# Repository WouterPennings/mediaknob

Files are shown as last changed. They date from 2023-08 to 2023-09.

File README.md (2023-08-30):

# Mediaknob

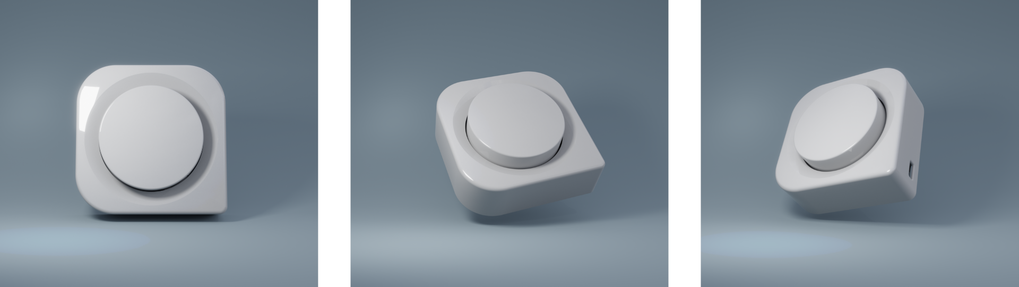
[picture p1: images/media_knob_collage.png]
mediaknob


This is a DIY media control knob for your computer. Adjust your volume, skip songs, or press & hold the knob for attention mode. 

Print the parts, solder the components, and upload the firmware. Go to [instruction.md](instructions.md) to see how to assemble and run the Mediaknob.

## Features

- **Turn Clockwise**: Turn volume up
- **Turn Counter-Clockwise**: Turn volume down
- **Single Click**: Pause/Play
- **Double Click**: Next song
- **Tripple Click**: Previous song
- **Long Click Hold**: Attention mode (Mutes volume while the button is pressed) 

## Acknowledgements

The knob is our first try at building a physical device. Although this is very different, the initial inspiration came from the [Smartknob](https://youtu.be/ip641WmY4pA?si=oMXHZ1xV06TqFzg1). This project was a relatively simple test to get our feet wet in 3D printing and electronics.

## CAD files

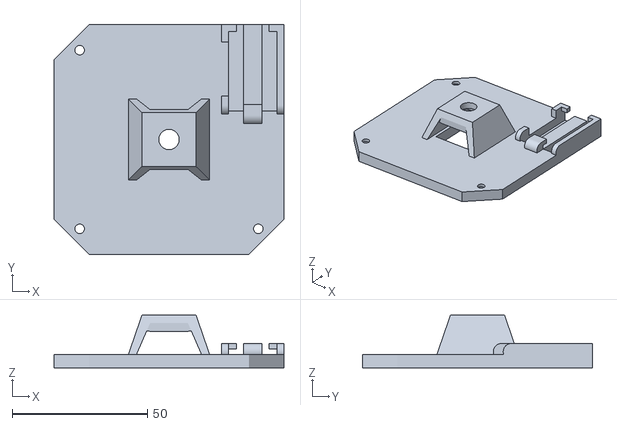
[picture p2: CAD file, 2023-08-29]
3d/main_board.stl
85.0 x 85.0 x 19.5

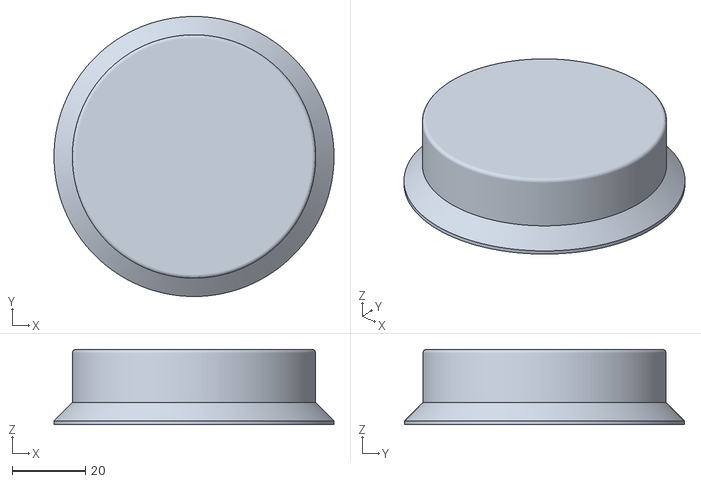
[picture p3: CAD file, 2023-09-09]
3d/button_wide.stl
76.5 x 76.5 x 20.5

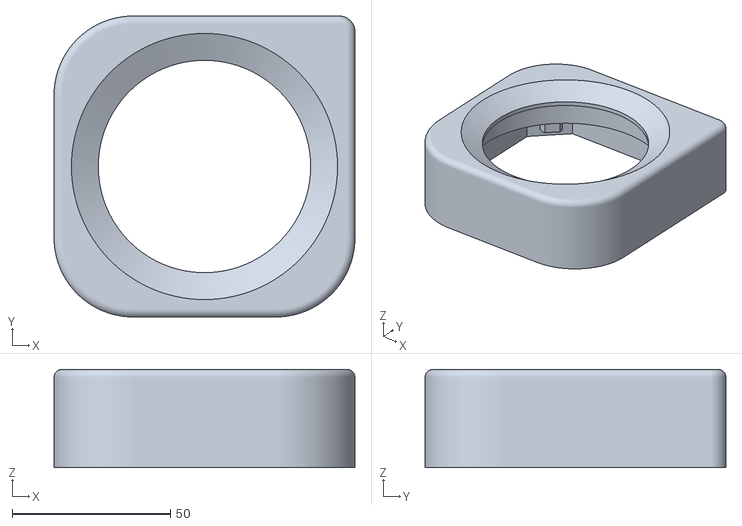
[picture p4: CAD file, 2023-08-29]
3d/chassis.stl
95.0 x 95.0 x 31.0

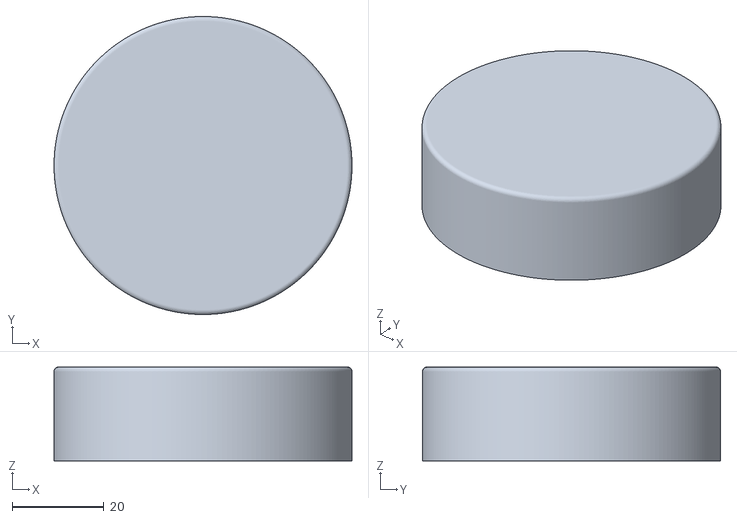
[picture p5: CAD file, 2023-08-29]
3d/button.stl
65.0 x 65.0 x 20.5

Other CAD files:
3d/mediaknob.f3d

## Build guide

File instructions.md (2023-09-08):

# Instructions

You will find the component list, schematics, and instructions to build the media knob here.

## Components

- Arduino Pro Micro 5V ([Sparkfun](https://www.sparkfun.com/products/12640))
  - Make sure you buy a Pro Micro with identical dimensions to the Sparkfun one
- EC11 Rotary encoder ([Aliexpress](https://nl.aliexpress.com/item/1005002802225957.html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))
- All 3D printed parts STL files can be found in [3d](/3d)
- Some electrical wire or five jumper wires
- M3 nuts + M3&ast;20 bolts (M3&ast;10 bolts are also fine, but not preferred as M3&ast;20 bite into the plastic creating a more secure bond.)
- Micro USB cable

### Equipment

- 3D printer, or use a 3D printing service.
- Soldering iron
- Solder
- Flux, not necessary, but could help
- Hex driver

## Electrical Schematic

The pins of the rotary encoder in this schematic are connected to `D2`, `D4`, and `D6`. You could use other pins, even the analog ones; however, you would have to refactor the code accordingly.

<div>
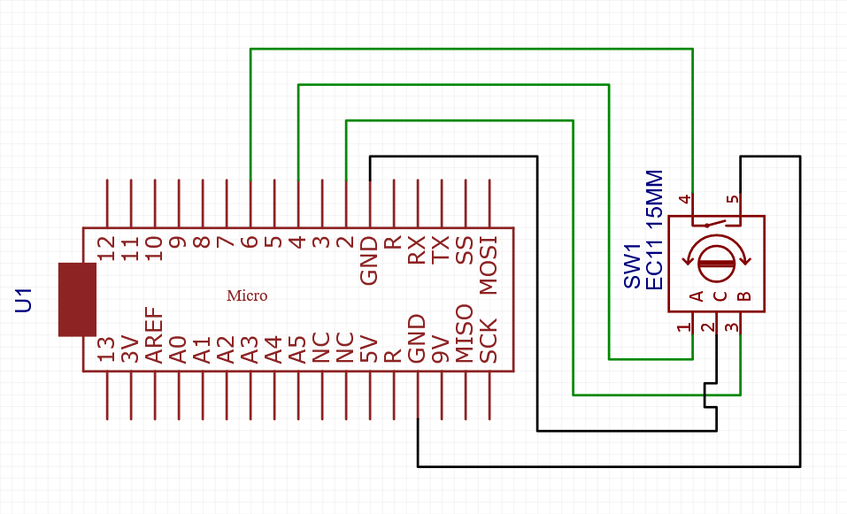
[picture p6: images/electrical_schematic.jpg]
  
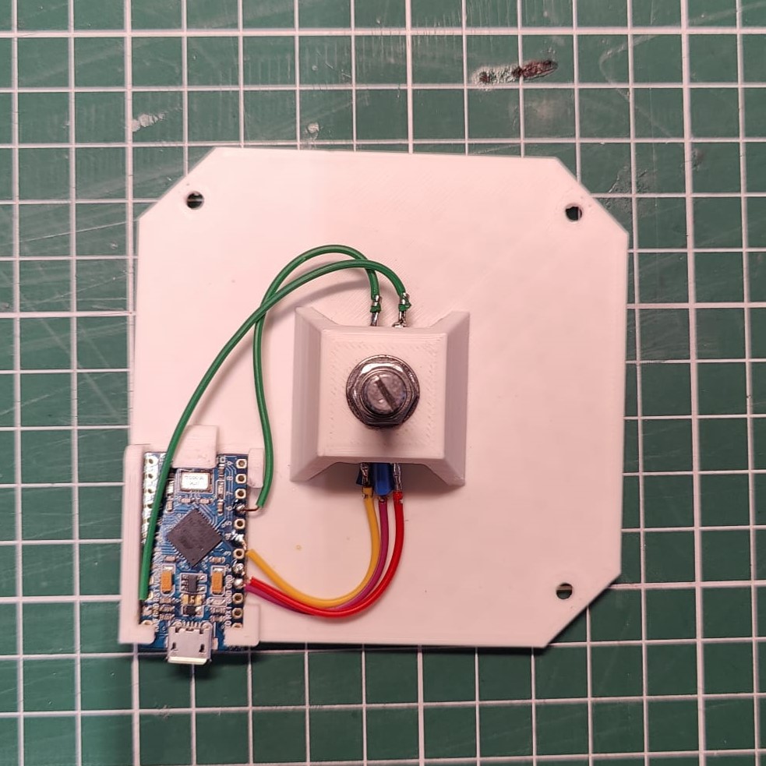
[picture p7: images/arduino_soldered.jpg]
  
</div>

## Assembly Guide

1. 3D print all the components.
   - **Tip**: To achieve a more premium and robust feel, increase the infill or even set it to 100%, as that will increase the weight and structural integrity of the chassis of the button.
2. Melt one M3 nut into each pillar of the [chassis](3d/chassis.stl) using a hot soldering iron.

<div>
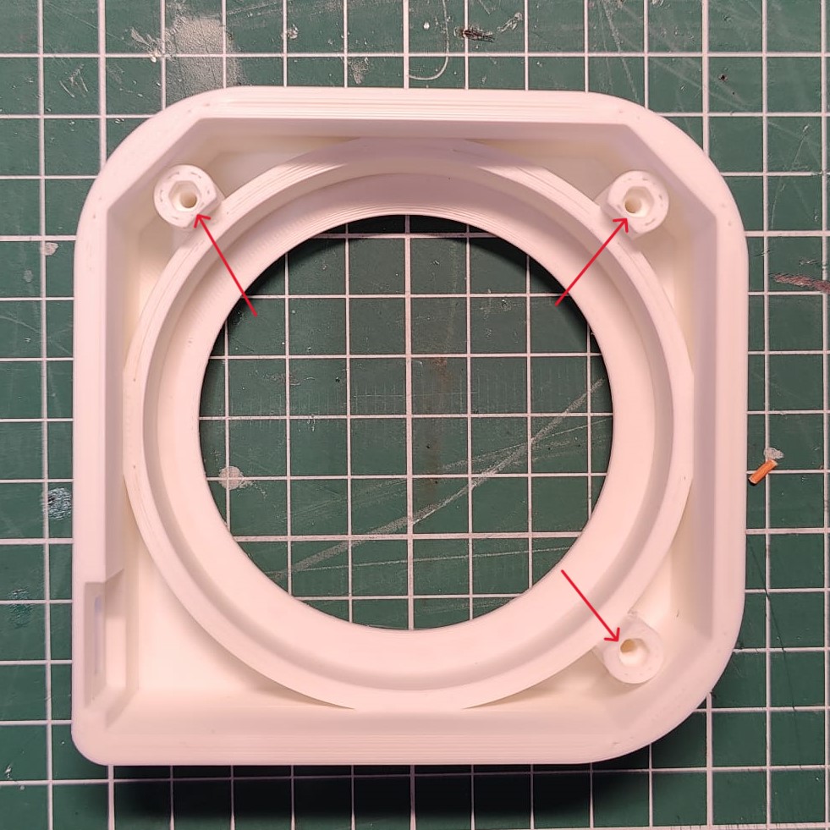
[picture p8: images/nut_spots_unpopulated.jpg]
   
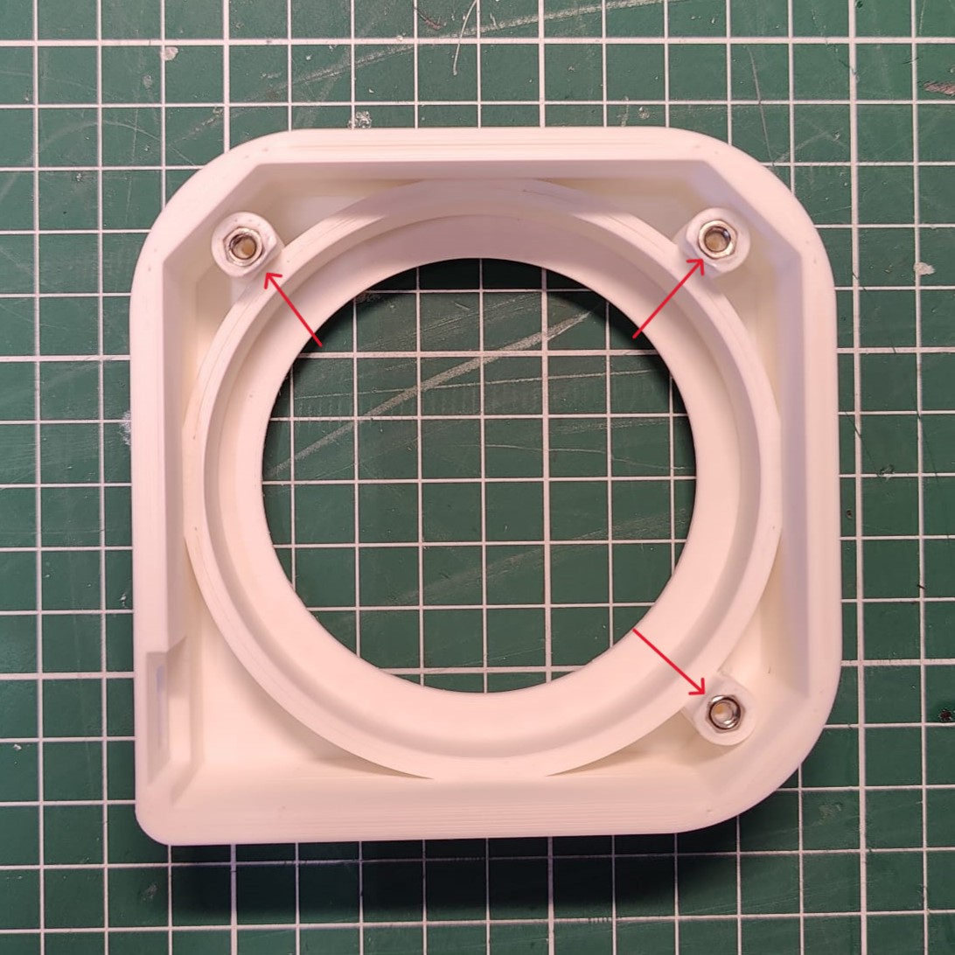
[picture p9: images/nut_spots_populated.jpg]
   
</div>

3. Screw the rotary encoder into the [main board](3d/main_board.stl), and insert the Arduino Pro Micro into its slot.

<div>
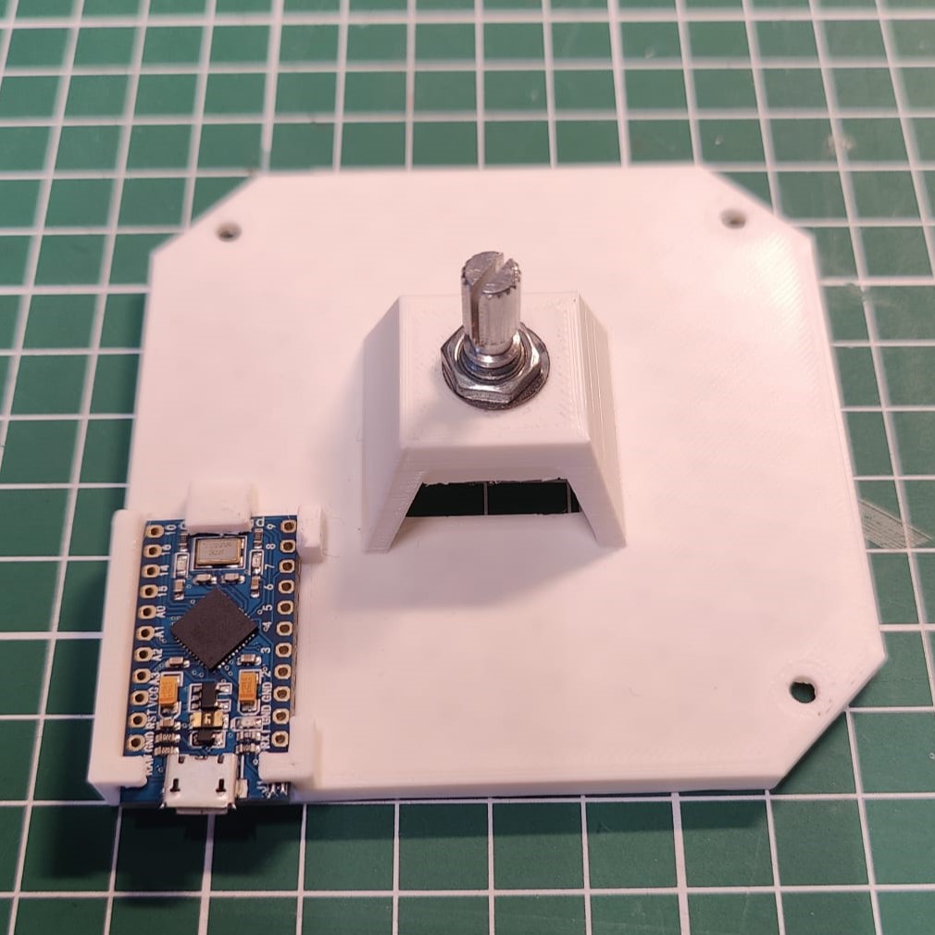
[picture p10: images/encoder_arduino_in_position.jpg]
   
</div>

4. Bend the pins of the rotary encoder so they are pointing outwards to make soldering of the wires easier. The best and safest way to achieve this is with a flat head screw driver, with which you carefully pry the pins away from the encoder plastic enclosure.

<div>
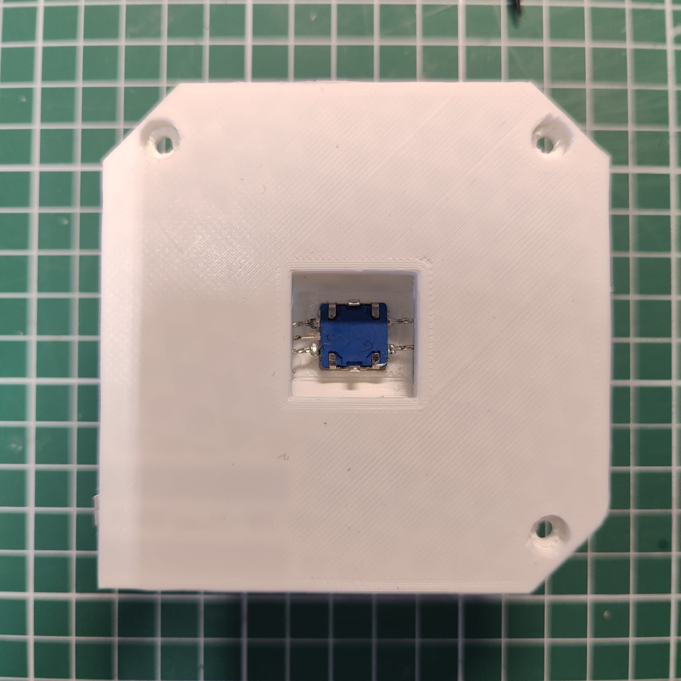
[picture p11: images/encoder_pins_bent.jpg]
   
</div>

5. Solder the five rotary encoder pins to the correct pins of the Arduino. Follow the schematic given earlier.
   - Soldering to a rotary encoder can sometimes be tedious. If you are a beginner or need help, follow [this guide on YouTube](https://youtu.be/2pfKgR3CWr4?si=yPZcE0ex2ldTHdDo).

<div>
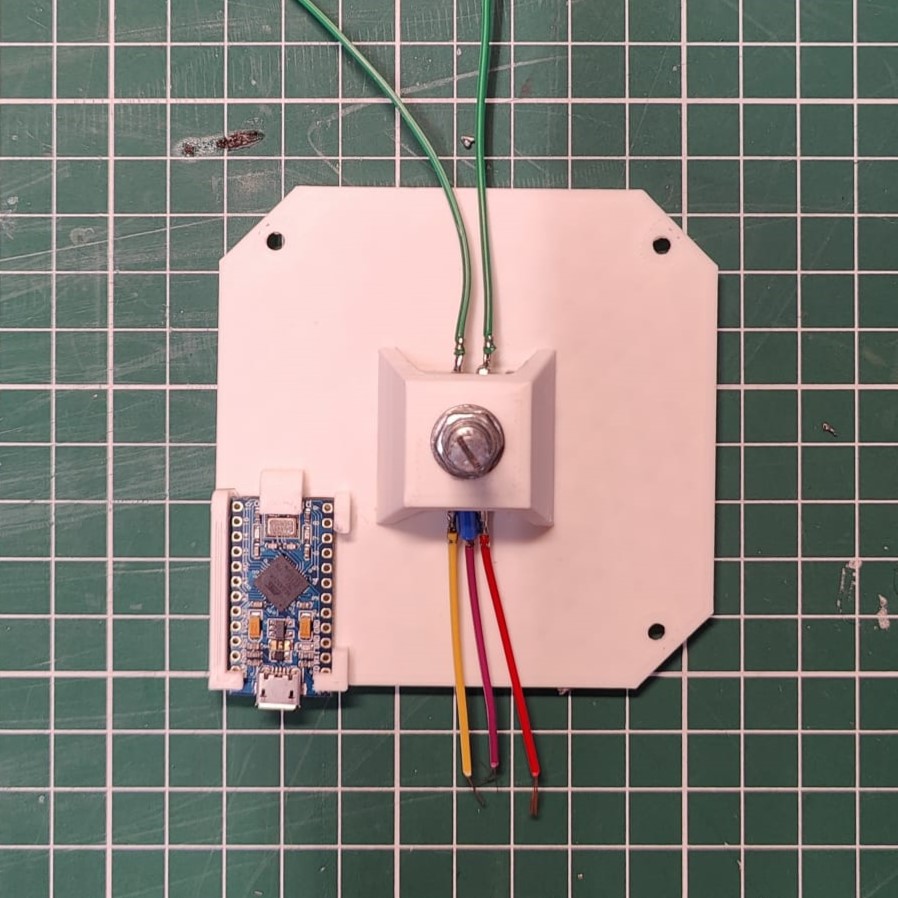
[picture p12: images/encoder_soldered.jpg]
   
   
</div>

6. Upload the firmware and test all functionality of the knob. This way, you know if something is wrong before tightening the bolt and attaching the button.
   - Steps to upload the firmware are given at the bottom of this page.
7. Bolt the [chassis](3d/chassis.stl) to the [main board](3d/main_board.stl) and attach the [button](3d/button.stl) to the shank of the rotary encoder.

<div>
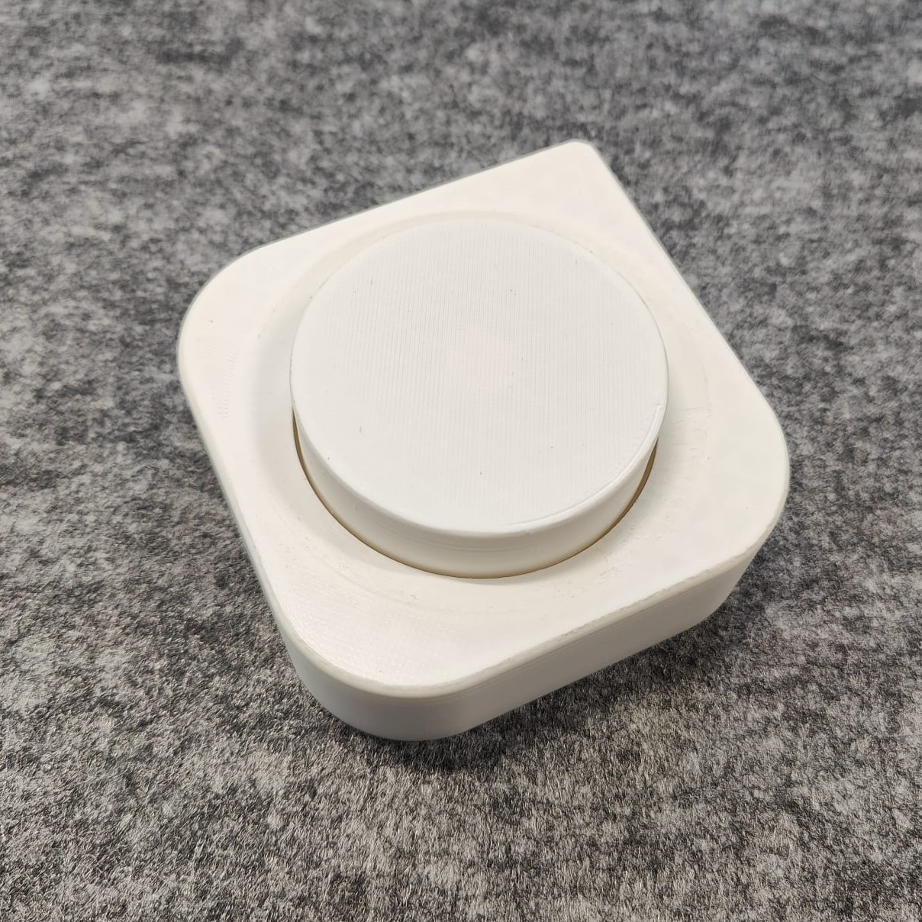
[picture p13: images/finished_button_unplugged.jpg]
   
</div>

### Upload Firmware

First, make sure that you have soldered your knob completely.

1. Clone this repository: `git clone https://github.com/WouterPennings/mediaknob.git`
2. Install [Arduino IDE 2.X](https://www.arduino.cc/en/software)
3. Install the `Button2` and `HID-Project` on the left side of the screen in the `Library` tab
4. Plug your Arduino Pro Micro into your computer using the Micro USB cable, and select the correct COM port in the Arduino IDE.
5. Press the `Upload` button and wait until the code is compiled and uploaded to your Arduino

> **Tip**: Use the serial monitor to debug if your knob shows unexpected behavior.

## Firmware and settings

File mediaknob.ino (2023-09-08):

#include "HID-Project.h"  // Link to library: https://github.com/NicoHood/HID
#include "Button2.h"      // Link to library: https://github.com/LennartHennigs/Button2

/* ==========================================================================
=========== BEGIN OF DEVICE CONFIG  =========================================
=============================================================================
Below is a list of all possible actions:
  MEDIA_FAST_FORWARD
  MEDIA_REWIND
  MEDIA_NEXT
  MEDIA_PREVIOUS
  MEDIA_STOP
  MEDIA_PLAY_PAUSE
  MEDIA_VOLUME_MUTE
  MEDIA_VOLUME_UP
  MEDIA_VOLUME_DOWN
  CONSUMER_EMAIL_READER
  CONSUMER_CALCULATOR
  CONSUMER_EXPLORER
  CONSUMER_BROWSER_HOME
  CONSUMER_BROWSER_BACK
  CONSUMER_BROWSER_FORWARD
  CONSUMER_BROWSER_REFRESH
  CONSUMER_BROWSER_BOOKMARKS 
  (For more info on the Consumer API: https://github.com/NicoHood/HID/wiki/Consumer-API) */
#define SINGLE_PRESS      MEDIA_PLAY_PAUSE  // Quick press and release
#define DOUBLE_PRESS      MEDIA_NEXT        // Two quick presses and releases
#define TRIPPLE_PRESS     MEDIA_PREVIOUS    // Three quick presses and releases   
#define HOLD              MEDIA_VOLUME_MUTE // Press button and do not release, action is reverse when button is release (Attention mode)
#define RIGHT_TURN        MEDIA_VOLUME_UP   // Turn button clockwise
#define LEFT_TURN         MEDIA_VOLUME_DOWN // Turn button counter-clockwise

/* ==========================================================================
===========  END OF DEVICE CONFIG  ==========================================
===========================================================================*/

// Pins on Arduino Micro to which things are connected to
#define BTN_PIN 6
#define ROT_PIN_A 4 // If volume is lowered if turned clockwise, switch values of ROT_PIN_A and ROT_PIN_B around.
#define ROT_PIN_B 2

Button2 button;

void setup() {
  Serial.begin(115200);
  Serial.println("MediaKnob is starting up...");

  button.begin(BTN_PIN);
  button.setClickHandler(click);
  button.setDoubleClickHandler(doubleClick);
  button.setTripleClickHandler(trippleClick);
  button.setLongClickDetectedHandler(LongClickDetected);

  button.setLongClickTime(500); // Default LongClickTime is 200 ms

  pinMode(ROT_PIN_A, INPUT_PULLUP);
  pinMode(ROT_PIN_B, INPUT_PULLUP);
}

uint8_t has_turned = false;
uint8_t right_turn = false;

void loop() {
  button.loop();
  handle_rotary();

  // Logging
  if(has_turned) {
    Serial.print("Clockwise turn: ");
    Serial.println(right_turn);
  }

  // Executing HID commands to device, action per input is configured at top of the file
  if(has_turned && right_turn) Consumer.write(RIGHT_TURN);
  else if(has_turned && !right_turn) Consumer.write(LEFT_TURN);

  delay(5);
}

void click(Button2& btn) {
  Serial.println("Single press");
  Consumer.write(SINGLE_PRESS); 
}

void doubleClick(Button2& btn) {
  Serial.println("Double press");
  Consumer.write(DOUBLE_PRESS);
}

void trippleClick(Button2& btn) {
  Serial.println("Tripple press");
  Consumer.write(TRIPPLE_PRESS);
}

void LongClickDetected(Button2& btn) {
  Serial.print("Long Pressed ");
  Consumer.write(HOLD);

  while (btn.isPressed()) {
    delay(10);
    Serial.print(".");
    button.loop();
  }

  delay(100); 

  Serial.println("Long Unpressed");
  Consumer.write(HOLD);
}

int aState;
int aLastState; 

void handle_rotary() {
  aState = digitalRead(ROT_PIN_A);
  //Encoder rotation tracking
  if (aState != aLastState) { 
    has_turned = true;
    right_turn = digitalRead(ROT_PIN_B) == aState;
  } else {
      has_turned = false;
      right_turn = false;
  } 
  aLastState = aState;
}

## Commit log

2023-08-29 3d files + source code
    [button.stl, chassis.stl, main_board.stl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]
2023-08-30 Double, tripple and hold programmed, added electrical schematics, and uploading instructions
2023-09-08 updated wiki, images of assembly
2023-09-09 button design mitigating pro micro led bleed
    [button_wide.stl]
